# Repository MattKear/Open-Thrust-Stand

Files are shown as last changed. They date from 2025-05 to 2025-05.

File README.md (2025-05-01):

# Open Thrust Stand

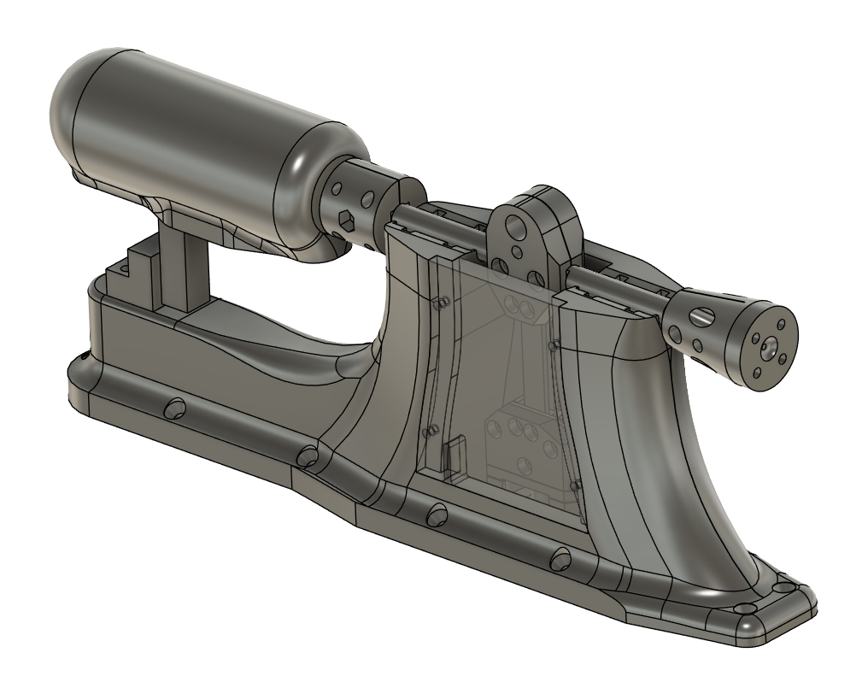
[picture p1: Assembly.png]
Assembly Image

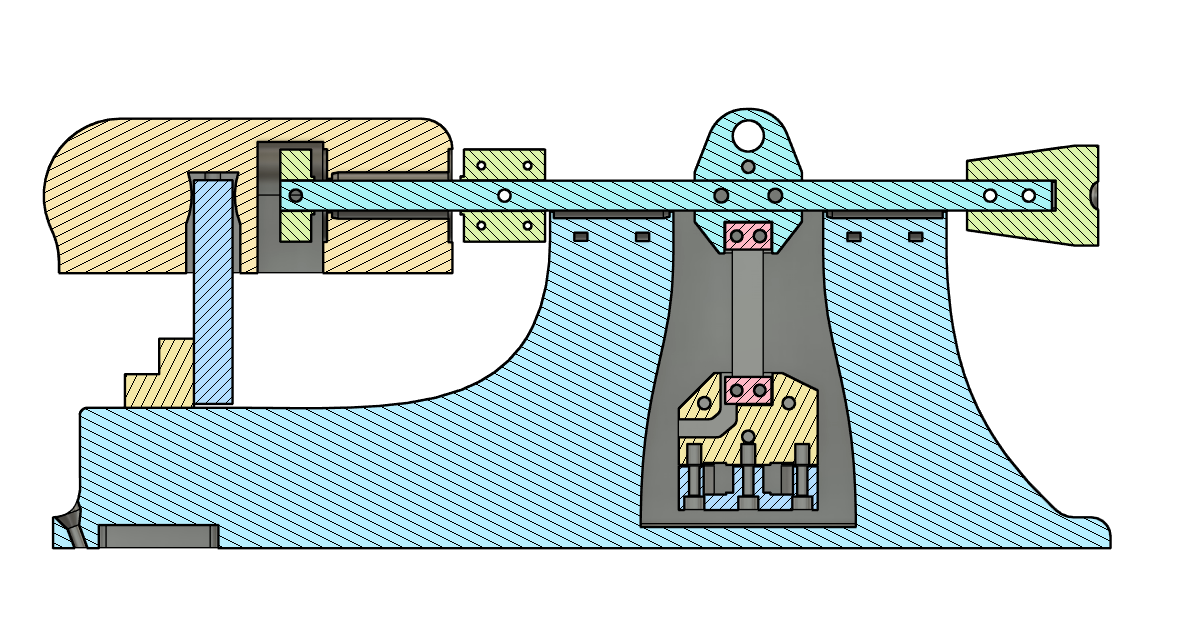
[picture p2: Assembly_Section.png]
Assembly Image


This is a repo of parts, scripts, and information about the ArduPilot-based thrust stand.

The point of this project was to produce a low-cost thrust stand capable:
- Measuring thrust and torque.
- Being controlable from ArduPilot.
- Providing data that can be used for calculating the thrust linearisation coefficient needed for fixed-pitch lifting rotors on ArduPilot vehicles.

Video of original talk: [Youtube Link](https://www.youtube.com/watch?v=xQXkWjY6EkU&list=PLC8WVaJJhN4zE8bW97rS3cNFjsDg0rOaD&index=25)

## Disclaimer
- This project should not be considered as a step-by-step guide.
- It should be considered a difficult project, with numerous tools required to create the final object.
- With 3D prints being in the primary load path, the strength of your parts will vary based on your choosen materials, printer settings, and the printer itself.  Please take care when testing, I accept no liability for any injuries or damage caused.

## License
- **Parts:** CC-BY-SA Creative Commons Attribution Share Alike (https://creativecommons.org/licenses/by-sa/4.0/deed.en)
- **Scripts/Code:** GPLv3 (https://www.gnu.org/licenses/gpl-3.0.en.html)

## Known Design Flaws

Before you start building this thrust stand, you should be aware of some of the flaws with this current design.

1) There is significant rotor blockage from the thrust stand base.  This will effect the measurement of the generated thrust.  The measurements are therefore useful for relative comparisons between propulsion systems that have been measured on this stand.  The blockage does introduce some error in the measurement.  That being said, I found that it produceses reliable and repeatible measurements, you just need to be aware when comparing to other data sets or considering the installed thrust on your vehicle.

2) This design does use one aluminium part from a cheap thrust stand I purchased as part of the background reasearch for this project.  A new part needs to be designed to replace this.  The part in question is the [load cell mount](./Thrust%20Load%20Cell%20Assembly/Load%20Cell%20Mount%20-%20Alu.step)

## Hardware Parts Needed
- M3 & M2 heat set inserts
- Various M3 & M2 allen bolts
- 2x Load Cells
- Wood Screws
- Bearings (Ball Bearings, Thrust Bearings, & Linear Bearings or Graphite Bearings)

>[!NOTE]
>These parts do not include parts needed for the archived enclosure.   

## Electronic Parts Needed
- [SparkFun Qwiic Scale - NAU7802](https://thepihut.com/products/sparkfun-qwiic-scale-nau7802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)
- SPST Switch (Hardware Safety Switch)
- Addressable LED strip supported by ArduPilot (e.g. WS2812b)
- Flight controller that is supported by ArduPilot and has sufficient memory to run scripting. (e.g. CubeOrange or MATEK H743)

## Tools Needed:
- 3D Printers (Mostly FDM but Resin SLA was used for LED Lenses in Enclosure)
- Angle grinder or other form of grinder
- Drill
- Screw Drivers
- Allen Keys
- Soldering Iron

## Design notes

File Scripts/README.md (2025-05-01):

# Thrust Stand
The scripts described here, utilise ArduPilot's Lua scripting enviroment to effectively convert ArduCopter into a Thrust Stand.

This has the advantage that the thrust stand will work with any ESC/protocol that ArduCopter supports.  Also, it allows for the script/workflow for to be easily customized to utilize all peripherals and sensors that are supported by ArduCopter.  For example, to measure RPM, just add an RPM sensor/ESC telemtry and the data will be added to the ArduCopter log.  Want to use WiFi telemetry to wirelessly operate the thrust stand? simply add an already supported wifi radio.

## Setup Instructions

Minimum hardware requirements:
- Toggle Switch - Configured as button 1 in AP button library.
- 10 Addressable LEDs for throttle bar. (not used in Thrust_Stand_Simple.Lua)
- SparkFun Qwiic Scale - NAU7802.  Only 1 is required for Thrust only measurements. A second is required for the optional torque measurement.  Note: to use two of these load cells either your flight controller must have 2 I2C buses available or you need an MUX, as the addresses are not configurable on those devices.

Firmware requirements:
- Thrust_Stand.Lua is more advanced and requires building copter from [this branch](https://github.com/MattKear/ardupilot/tree/Thrust_Stand_XL) to provide access to the thrust linearisation lua bindings that I have added.
- Thrust_Stand_Simple.Lua should run on stable copter (4.4 onwards).

## Connections & Setup
- Thrust load cell amplifier must be connected to I2C bus 1.
- Optional Torque load cell amplifier must be connecter to I2C bus 2 and `THST_ENAB_TORQ` must be set to 1.
- The ESC should be plugged into the flight controller output that you would use normally for flight (e.g. Servo output, CAN, etc) and configured as the `Motor1` (33) output. As this script is using ArduCopter, all throttle protocols supported by ArduCopter are supported by this script.
- A toggle switch must be configured as button 1, to act as a safety switch (see: https://ardupilot.org/copter/docs/common-buttons.html)

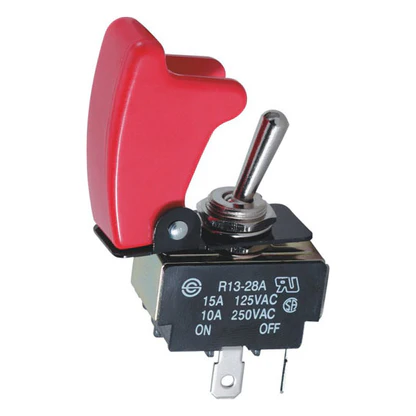
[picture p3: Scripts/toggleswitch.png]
Example toggle switch


## Calibrations

The load cell outputs a unitless number that requires calibration parameters to convert to loads in your desired units.  To calibrate, apply known loads to the load cells to derive the necessary calibration parameters.  For each load cell a gradient and an offset are required.  The calibration parameters to be set are:
- **`THST_CAL0_THST`:** Thrust load cell calibration, zero offset.
- **`THST_CALM_THST`:** Thrust load cell calibration, gradient.
- **`THST_CAL0_TORQ`:** Torque load cell calibration, zero offset.
- **`THST_CALM_TORQ`:** Torque load cell calibration, gradient.

Apply a series of different loads (weights are often the easiest) and look at the corresponding `MAV_THST_RAW` or `MAV_TORQ_RAW` telemetry streams on the GCS.  Plotting raw output vs applied load should give you a straight line.  Calculate the gradient and zero offset using a line of best fit (linear regression).  Enter the obtained values into the parameters mentioned above.  Finally, re-apply a load and check either `MAV_THRUST` or `MAV_TORQUE` on the GCS to make sure that the reported value matches the applied load.

-  Raw measurement from the thrust load cell amplifier.
- **`MAV_TORQ_RAW`:** Raw measurement from the torque load cell amplifier.

## Example Test Run

1. Power on the flight controller.

2. Connect the GCS to the flight controller.  This can be in any means you would like, just like with a normal copter.  e.g. You can use USB, WiFi, or some other telemetry radio.

3. Power on your propulsion system with either a battery or power supply.

4.Set the flight mode that corresponds to the thrust stand mode that you would like to use.

5. Perform the remaining checks as suggested below to make sure your sensors are all reporting correctly.

6. When you are ready to start your test, toggle the safety switch to prepare the system for test.

7. Arm copter from the GCS and the test will begin.

8. Once the test has completed the throttle will hold at `MOT_SPIN_MIN`.  Toggle the safety switch.  This will both disarm ArduCopter and "Safe" the system. 

## Saftey Switch

The safety switch is there to provide a quick and easy way to stop the test in an emergency.  If at any point during the test there is an issue or you simply want to stop the test, flick the switch and the throttle will be instantly zeroed and ArduCopter will be disarmed.

>[!NOTE]
>If you arm the system with the switch still in the "Safe" position, the test will not begin until the switch has been moved to the "Active" position.

## Checklists

### Power on Checks
- Power on propulsion system (Battery or power supply)
- Check for correct voltage measurement.
- Check/set current limit (`THST_CUR_LIM`).

### “Pre-Flight” Checks
- Check thrust load cell reporting correctly (number is moving and in correct direction).
- if applicable, check torque Load cell reporting correctly (number is moving and in correct direction).
- If applicable, check `RPM1_SCALE` = 1 is set for eRPM  measurement,
- Set `MOT_SPIN_MIN` (use Copter's motor test) [`THST_ENBL_TEST` = 1]
- Check/set for thrust linearisation enabled [`THST_USE_LIN`].  Pick whichever is appropriate for the test.
- Check `MOT_SPIN_MAX` = 1.0
- Check `MOT_PWM_MIN` (usually set 1000)
- Check `MOT_PWM_MAX` (usually set 2000)
- Run up to 50% throttle check.
- Calibrate Thrust and Torque load cells if necessary.

### Test Checks

- Set test mode.

#### Throttle Ramp Mode

-	Set `THST_HOLD_S` (s) to the length of time to hold throttle at each step.
-	Set `THST_MAX_THR` (%) [0 - 100] to set the max throttle.
-	Set `THST_RAMP_STEP` [0.01 - 1.0]

#### Transients / Step-Change Mode

-	Set `THST_HOLD_S` (s) to the length of time to hold the step change.
-	Set `THST_MAX_THR` (%) [0 - 100] to the max throttle to set the step change to.
-	Set `MOT_THST_HOVER` [0.0 - 1.0]
Note: Throttle will step hover throttle +/- (max throttle – hover).  Ensure set to allow symmetric steps.

#### Frequency Sweep / Throttle Chirp Mode
-	Throttle/thrust output is between MOT_SPIN_MIN and MOT_SPIN_MAX
-	Set `THST_HOLD_S`(s) to the length of time to hold the initial trim state. Usually set 3 s.
-	Set `THST_MAX_THR` (%) [0 - 100] to the max throttle to set the step change to.
-	Set `MOT_THST_HOVER` [0.0 - 1.0] this is the centre/mean of the sin wave
-	Set `THST_NSE_RAT` – the noise ratio or amplitude.
-	Set `THST_OMEGA_MIN` (rad/s) (default = 0.3)
-	Set `THST_OMEGA_MAX` (rad/s) (default = 12)

##### Test Procedure:

- Log air temperature, relative humidity, and pressure.
- Arm ArduCopter via GCS.
- Switch toggle safety switch.
- Throttle will ramp up and test will begin.
- Test will be performed  automatically, as per configuration.
- Throttle will ramp down and sit at `MOT_SPIN_MIN` once test has completed.
- Switch toggle safety switch to both safe and disarm system.

## Test Modes

Copter flight modes are used as a proxy for thrust stand modes. The below describes which copter modes correlates to the thrust stand modes.

You must set the flight modes below, via the GCS, to use the corresponding thrust stand modes described below.

- Ensure that you have set the mode via the GCS before you arm the thrust stand, to perform the desired test.

- **Stabilise:** Stepped throttle ramp for expo calculations
- **Alt_Hold** - Throttle mode hold, ramps to `THST_MAX_THR` and holds for `THST_HOLD_S`
- **Acro** - Throttle steps, ramps to `MOT_THST_HOVER`, and then step changes to `THST_MAX_THR`
- **Guided_NoGPS** – (System ID) Throttle chirps/frequency sweeps

## Parameter Definitions

- **`THST_CAL0_THST`:** Thrust load cell calibration, zero offset.
- **`THST_CALM_THST`:** Thrust load cell calibration, gradient.
- **`THST_CAL0_TORQ`:** Torque load cell calibration, zero offset.
- **`THST_CALM_TORQ`:** Torque load cell calibration, gradient.
- **`THST_CUR_LIM`:** Current limit. If battery monitor measures a current above this value the throttle will be instantly zeroed and the test will stop.  Safety switch has to be cycled to allow another test to start again.
- **`THST_MAX_THR`:** Maximum throttle used. In a ramp test the throttle will ramp between 0 and max.  In all other test modes the throttle will be constrained by this value. 0 to max throttle is within spin min and max.
- **`THST_HOLD_S`:** Hold time in seconds.  In ramp test, this is the step dwell time.  In the transient, step test, this is the dwell time to hold the throttle at between step inputs.
- **`THST_ENBL_TORQ`:** Used to enable use of 2nd load cell for torque measurements. 0 = disabled, 1 = enable torque.
- **`THST_ENBL_TEST`:** Set to 1 (allow) to enable copters motor test from the GCS.  Whenever a thrust stand run is started this param is automatically returned to 0 (disabled) with a set and save.  This is required to stop the script from overriding the output when copter is trying to do its motor test.
- **`THST_OMEGA_MIN`:** Minimum frequency (rad/s) for throttle chirp test.
- **`THST_OMEGA_MAX`:** Maximum frequency (rad/s) for throttle chirp test.
- **`THST_NSE_RAT`:** Noise ratio to be applied during chirp test. Ratio of max throttle.
- **`THST_RAMP_STEP`:** Spacing between throttle steps in ramp test mode.  E.g. 0.1 = 10% throttle steps.
- **`THST_USE_LIN`:** – 0 = throttle control, 1 = thrust control.  When enabled thrust to throttle linearisation from multi-rotor code is used. **(Not enabled in Thrust_Stand_Simple.lua)**

- **`MOT_PWM_MIN`:** Copter `MOT_PWM_MIN` used in throttle output calculation. See here for definition: https://ardupilot.org/copter/docs/parameters.html#mot-pwm-min-pwm-output-minimum
- **`MOT_PWM_MAX`:** Copter `MOT_PWM_MAX` used in throttle output calculation. See here for definition: https://ardupilot.org/copter/docs/parameters.html#mot-pwm-max-pwm-output-maximum
- **`MOT_SPIN_MIN`:** Copter `MOT_SPIN_MIN` used in throttle output calculation. See here for definition: https://ardupilot.org/copter/docs/parameters.html#mot-spin-min-motor-spin-minimum
- **`MOT_SPIN_MAX`:** Copter `MOT_PWM_MIN` used in throttle output calculation. See here for definition: https://ardupilot.org/copter/docs/parameters.html#mot-spin-max-motor-spin-maximum

- **`MOT_THST_EXPO`:** Used in thrust linearisation calculation, if THST_USE_LIN is enabled.

- **`MOT_THST_HOVER`:** used for throttle step transient mode.  This is the middle throttle setting and the the throttle is stepped +/- `THST_RAMP_STEP` about this value.

## Live Outputs to GCS

Live telemetry data can be seen from the script. The following are output at 2 Hz:
- **`MAV_THST_RAW`:** Raw measurement from the thrust load cell amplifier.
- **`MAV_TORQ_RAW`:** Raw measurement from the torque load cell amplifier.
- **`MAV_THRUST`:** Calibrated thrust calculation from thrust load cell.
- **`MAV_TORQUE`:** Calibrated thrust calculation from torque load cell.

- This data can be viewed on the GCS just like any other telemetry data from Copter.  For example, in mission planner, the "Quick" tab will give numerical read outs and the "Tuning" graphs will plot the data trend vs time.

## Logging

All data is stored in ArduCopter *.bin log files. The thrust and torque data is stored in the **THST** log field.  All other data is stored in the usual log fields. E.g Battery monitor stores current and voltage data, RPM for rpm data etc.

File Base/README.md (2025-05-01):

# Thrust Strand Base

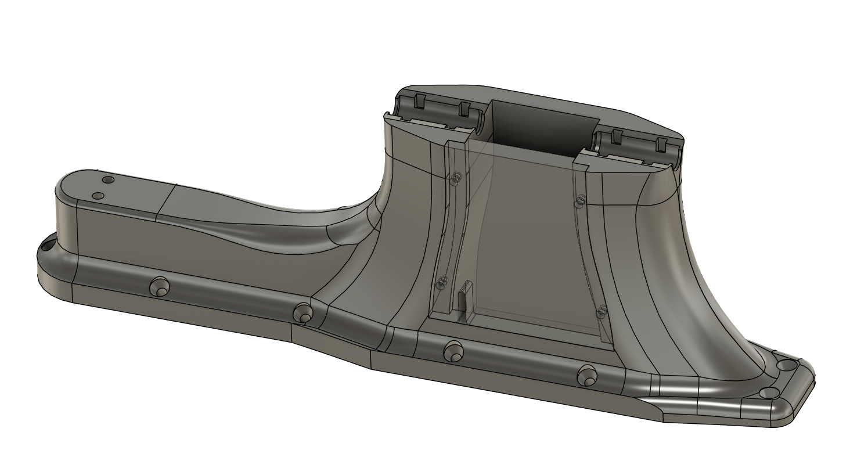
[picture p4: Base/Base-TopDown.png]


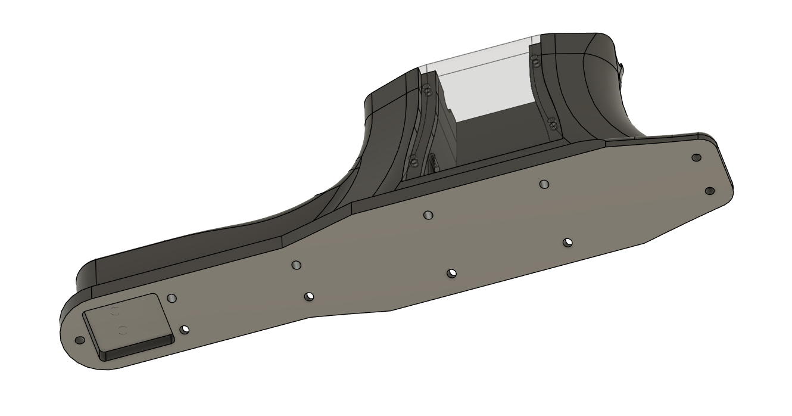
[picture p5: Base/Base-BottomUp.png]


Wood Screws are used to afix the base to a strong flat surface.

M2 bolts and heat-set inserts are used to secure the side cover in place.

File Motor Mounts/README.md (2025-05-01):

# Motor Mounts

The motor mounts are easily swappable, making it easy to test different motors.  Here are a few mounts that have already been made.

## 16 x 16 Hole Spacing
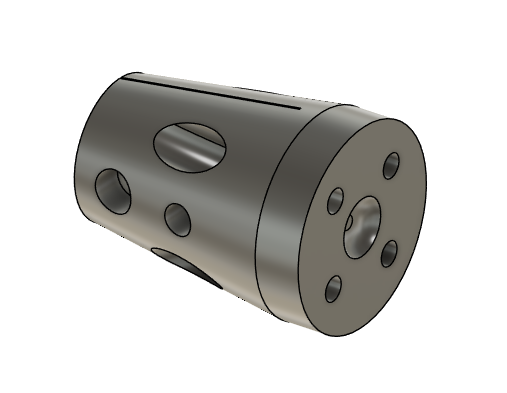
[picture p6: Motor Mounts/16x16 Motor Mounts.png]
16 x 16 Hole Spacing


## 19 x 19 Hole Spacing
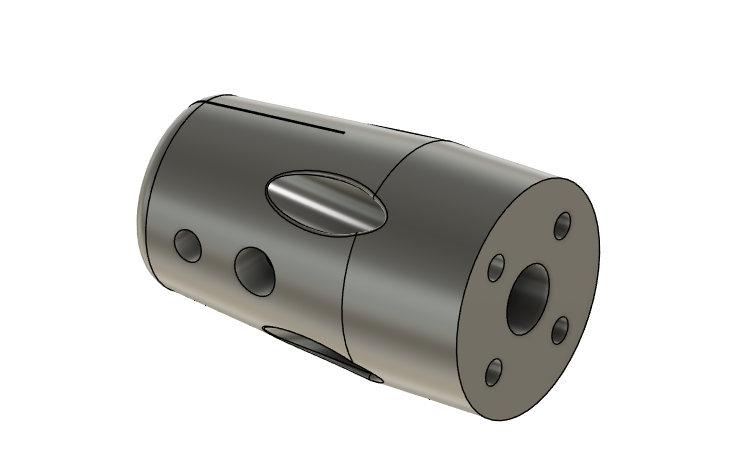
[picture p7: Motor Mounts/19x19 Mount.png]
19 x 19 Hole Spacing


## MAD Polar Motor Mount
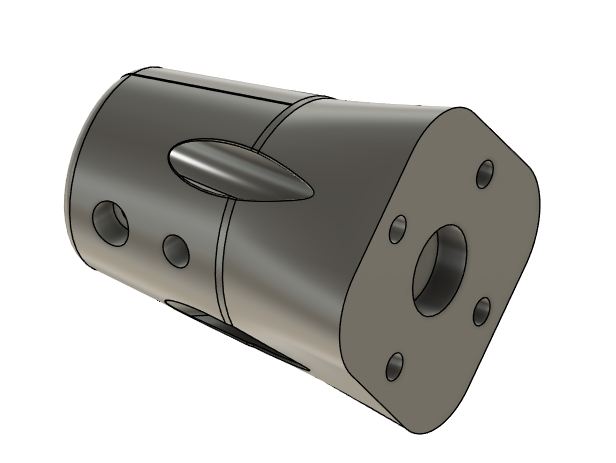
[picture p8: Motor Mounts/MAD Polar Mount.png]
MAD Polar Motor Mount


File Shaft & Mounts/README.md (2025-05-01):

# Shaft & Bearing Mounts

In this directory you will find the bearing retainers and the guides for grinding the flats into the linear rail. 

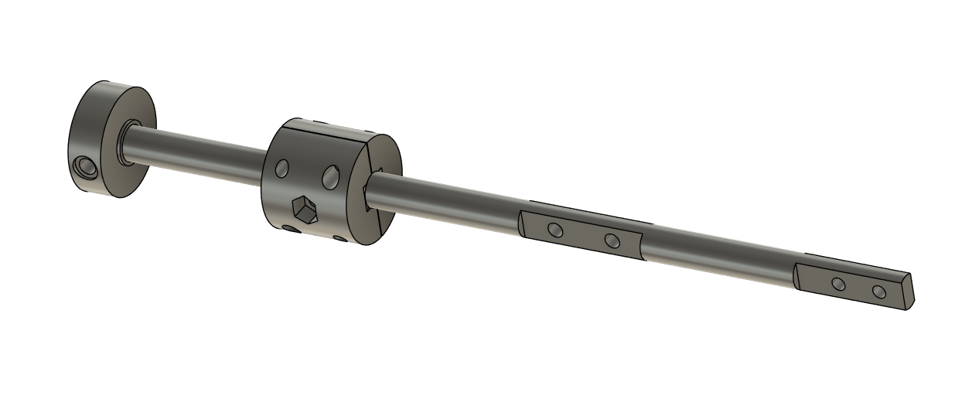
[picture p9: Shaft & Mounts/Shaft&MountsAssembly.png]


# Grinding Guides

The 3D printed grinding guides are used to clamp around the shaft and provide a guide of where to grind away the flats on the linear rail.

You will need to grind away the flats gradually, to avoid building up too much heat in the rail and the 3D prints.  Excessive heating of the rail could warp it and cause more friction in the system.  Melting of the 3D prints will lead to an inaccurate guide.

Rest assured, Once you have grinded past the hardend surface on the linear rail, the steel is quite soft beneath it, so it is easy to drill the holes in.

The holes in the guide are sized so that an M3 will bite into the plastic.  Heat set inserts are not needed in this part.

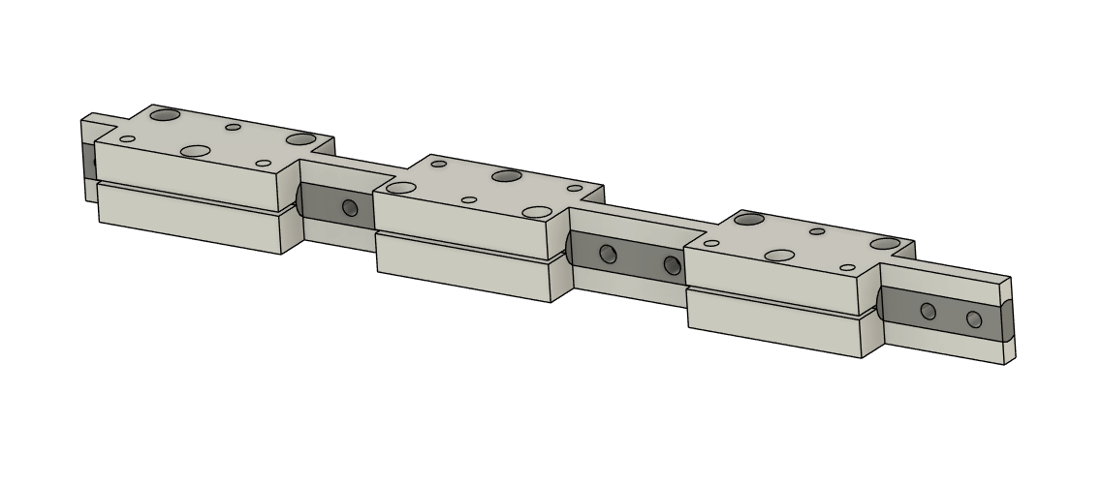
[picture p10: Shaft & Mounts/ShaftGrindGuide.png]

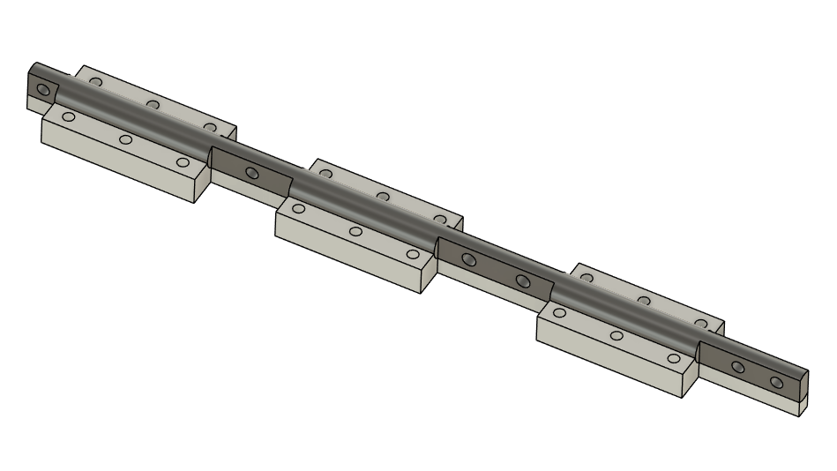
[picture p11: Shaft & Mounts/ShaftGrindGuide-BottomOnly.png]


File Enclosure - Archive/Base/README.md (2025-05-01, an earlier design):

# Enclosure Base

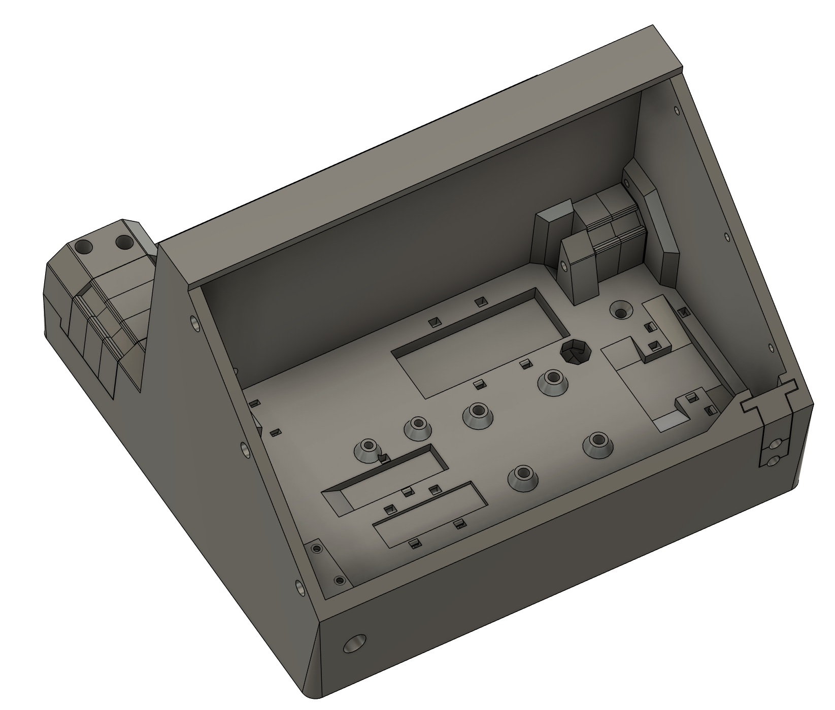
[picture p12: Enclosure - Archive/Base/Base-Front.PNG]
Enclosure Base Front

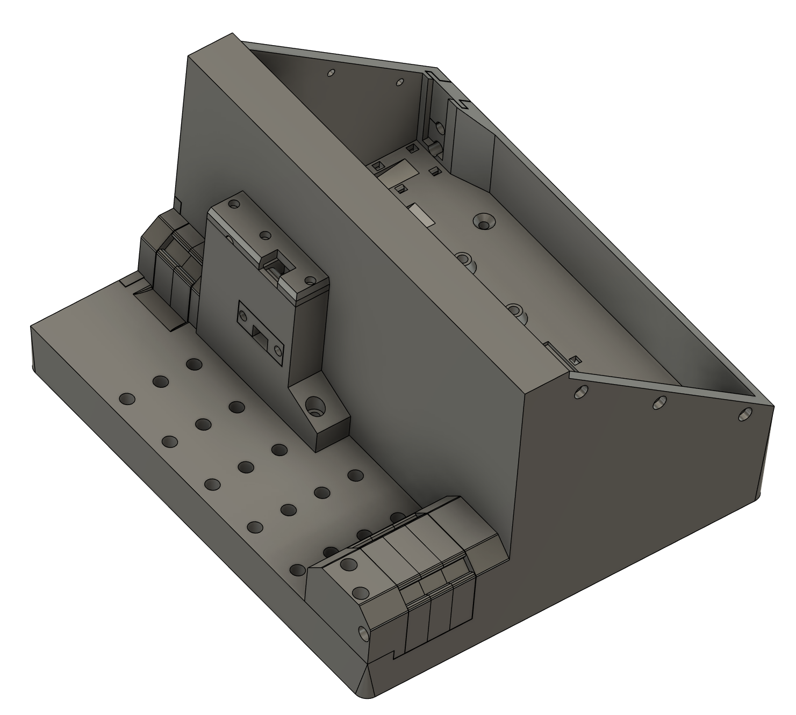
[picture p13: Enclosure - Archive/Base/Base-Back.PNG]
Enclosure Base Back


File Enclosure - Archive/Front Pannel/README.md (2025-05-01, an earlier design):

# Enclosure Front Pannel

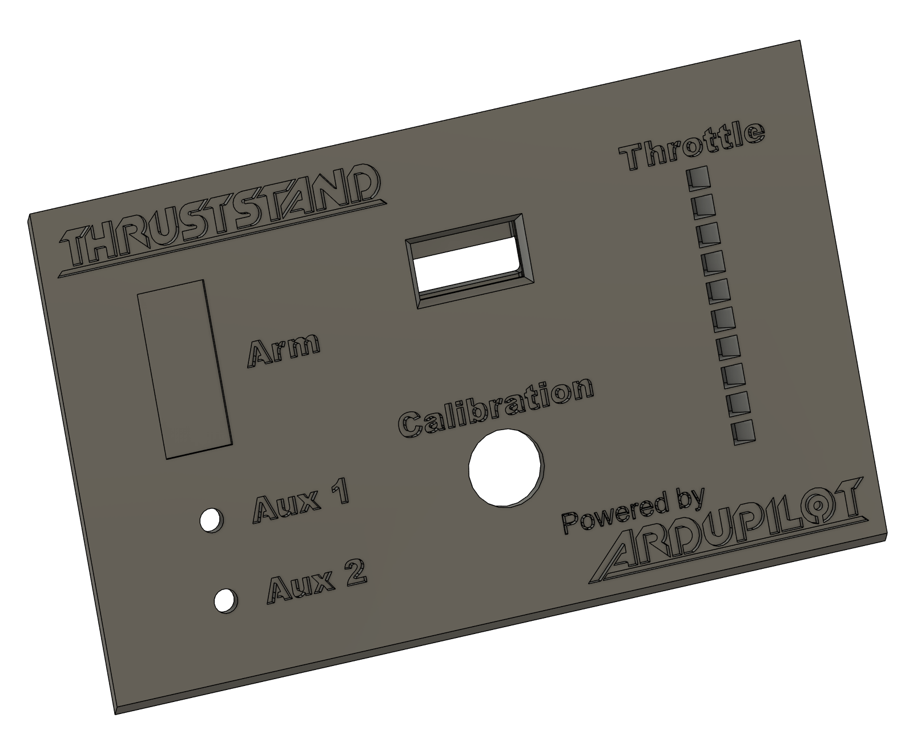
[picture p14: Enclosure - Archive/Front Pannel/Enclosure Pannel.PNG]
Enclosure Pannel


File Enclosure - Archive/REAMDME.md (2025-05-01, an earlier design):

# Enclosure

I have marked this part as `archived` as it is not particularly fit for purpose.  I do not use it anymore, and I would recommend that you just attach the parts to flat surface (this is what i do now). It makes it a lot easier for modifying and fiddling with the setup. You can always fix that surface into a project box should you wish.

If you use any of the later versions of the script I have posted, I have removed the use of the I2C screen and the calibration button.  I have moved to a process of using Mission Planned to control the thrust stand from instead so the screen and button were no longer needed.

I kept the arming switch and LED bar though.

I am posting these files here as some people may still want to make use of them.

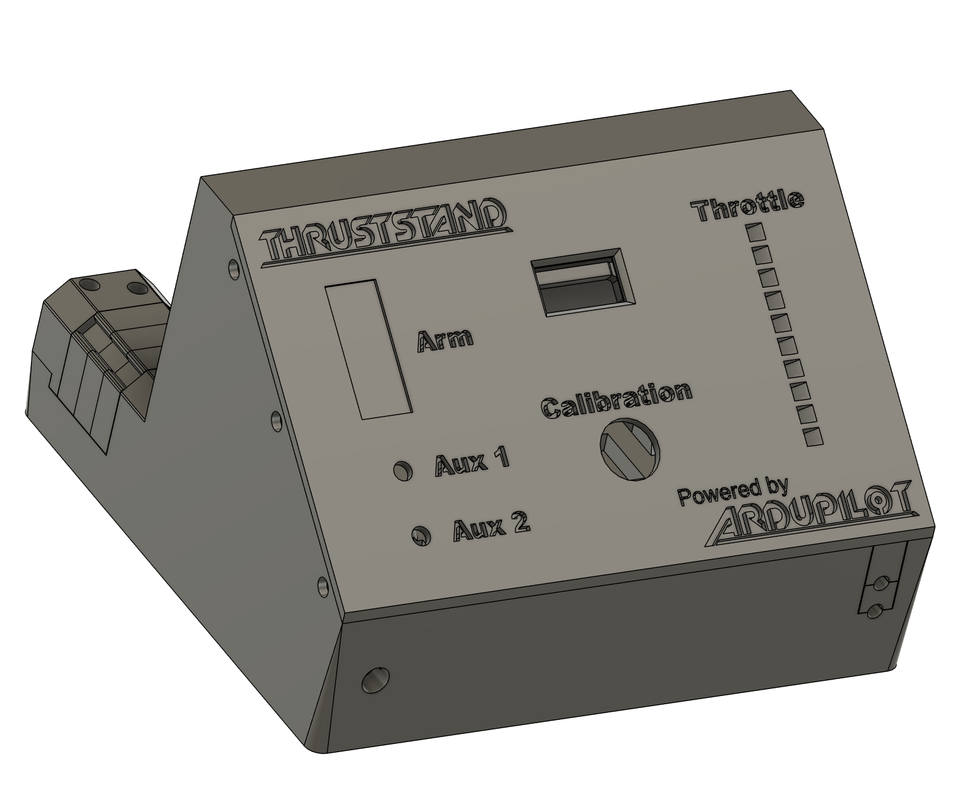
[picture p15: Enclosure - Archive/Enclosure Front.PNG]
Enlosure Front

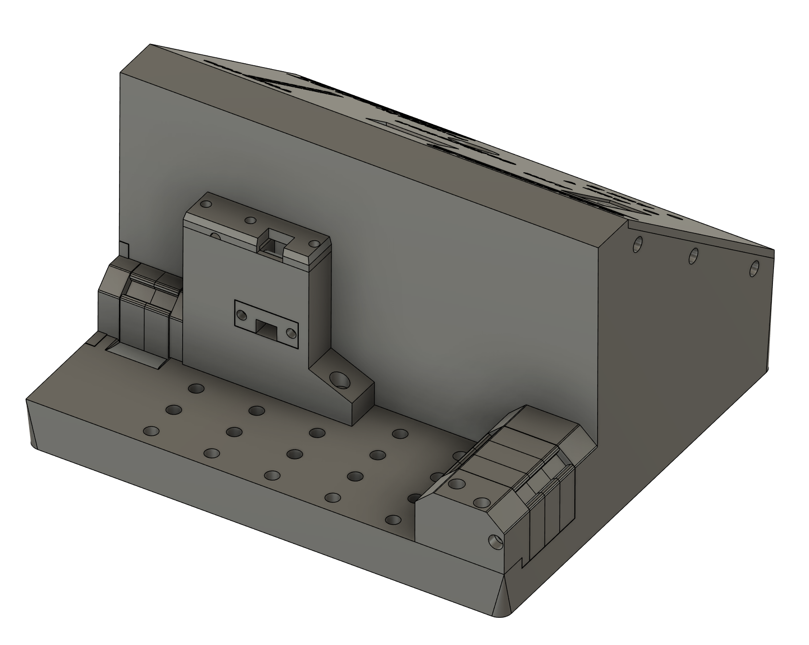
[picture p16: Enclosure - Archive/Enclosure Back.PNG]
Enlosure Back


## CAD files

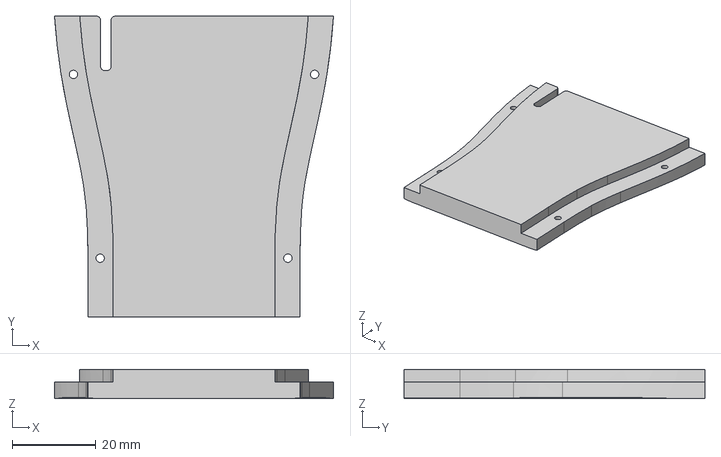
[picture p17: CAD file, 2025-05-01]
Base/Base Cover - 3D Print.step
66.6 x 71.8 x 7.00 mm

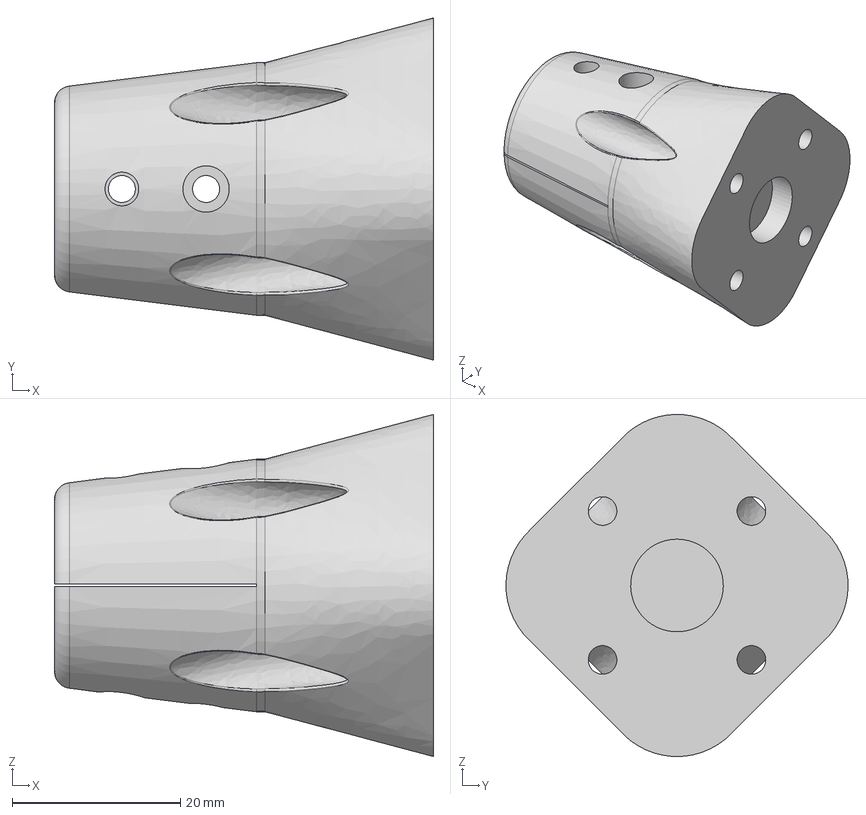
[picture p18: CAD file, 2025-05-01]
Motor Mounts/MAD Polar Mount - 3D Print.step
45.0 x 40.6 x 40.6 mm

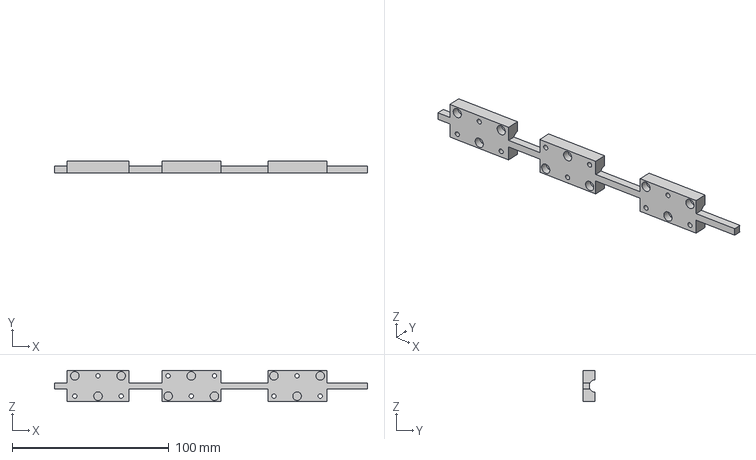
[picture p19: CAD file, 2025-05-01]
Shaft & Mounts/Shaft Grind Guide Top - 3D Print.step
200.0 x 7.60 x 20.0 mm

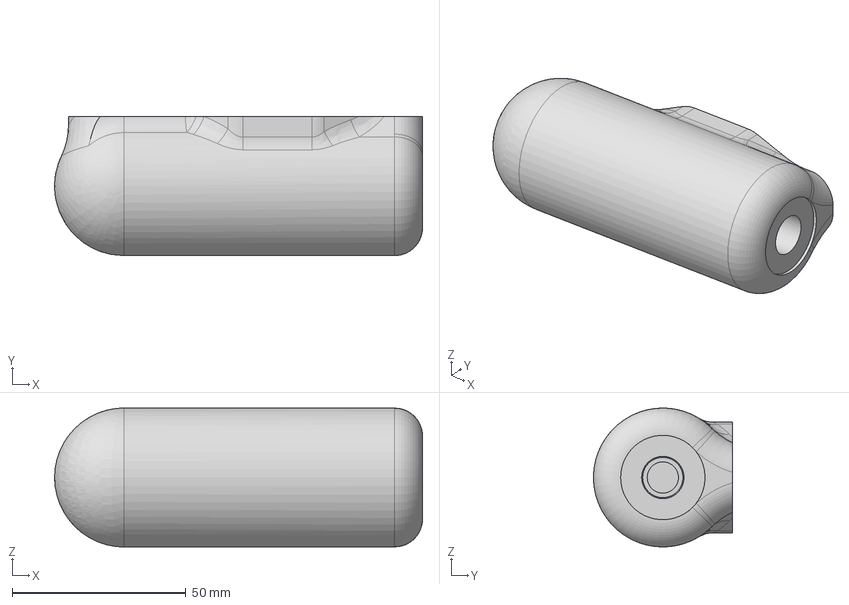
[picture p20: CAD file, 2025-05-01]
Thrust Load Cell Assembly/Thrust Cell Interface - 3D Print.step
106.0 x 40.1 x 40.0 mm

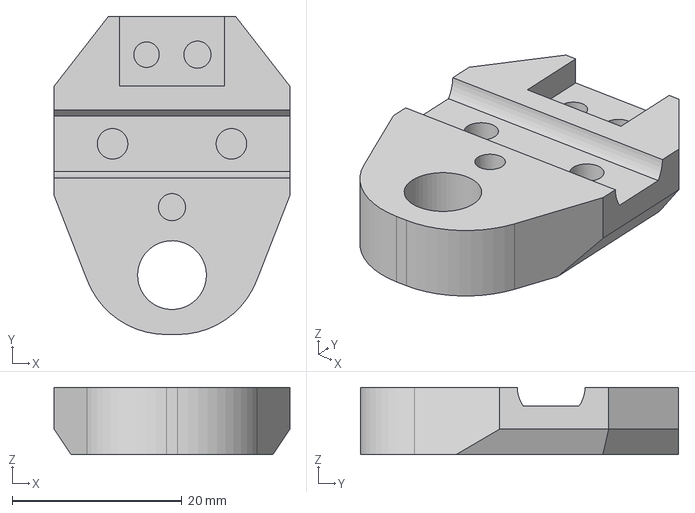
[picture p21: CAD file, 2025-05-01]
Torque Load Cell Assembly/TorqueShaftClampLeft-3DPrint.step
27.8 x 37.5 x 7.90 mm

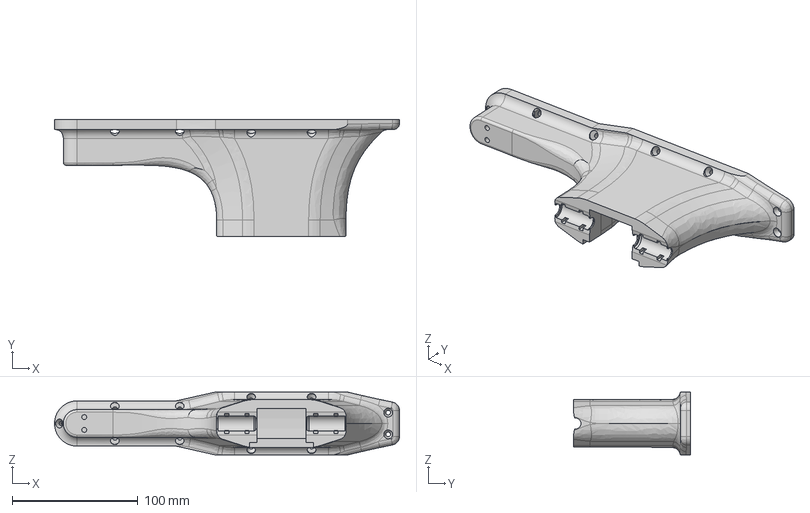
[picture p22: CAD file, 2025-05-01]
Base/Base Body - 3D Print.step
274.3 x 93.0 x 50.0 mm

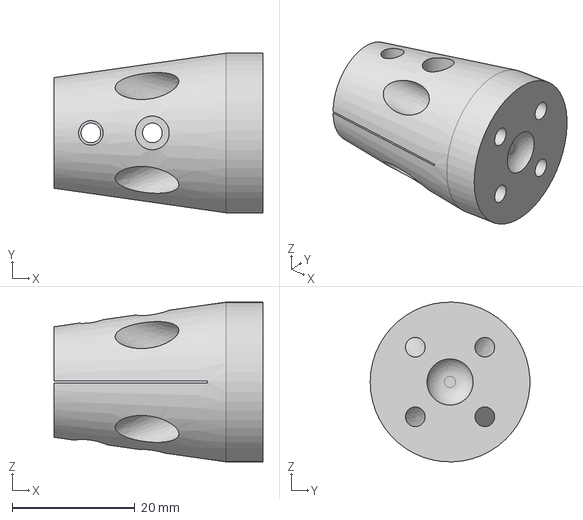
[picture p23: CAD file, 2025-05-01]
Motor Mounts/16x16 Motor Mount - 3D Print.step
34.0 x 26.0 x 26.0 mm

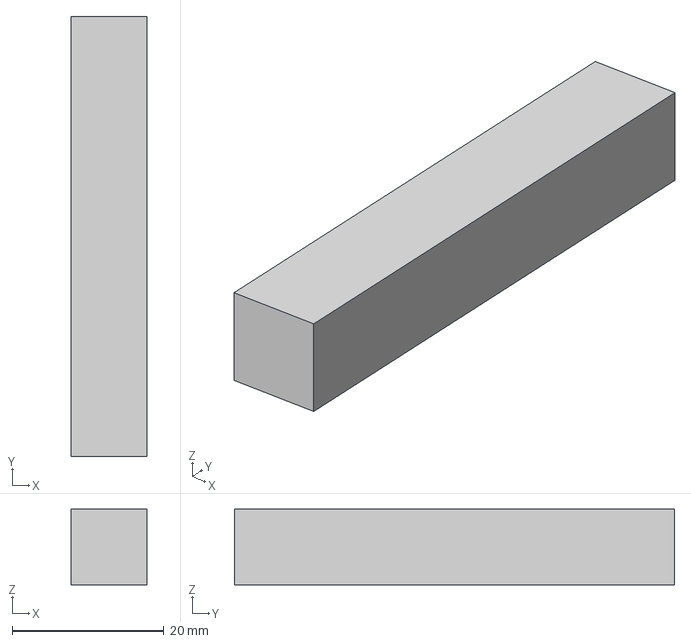
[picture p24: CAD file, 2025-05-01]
Thrust Load Cell Assembly/Load Cell Stand In.step
10.00 x 58.0 x 10.0 mm

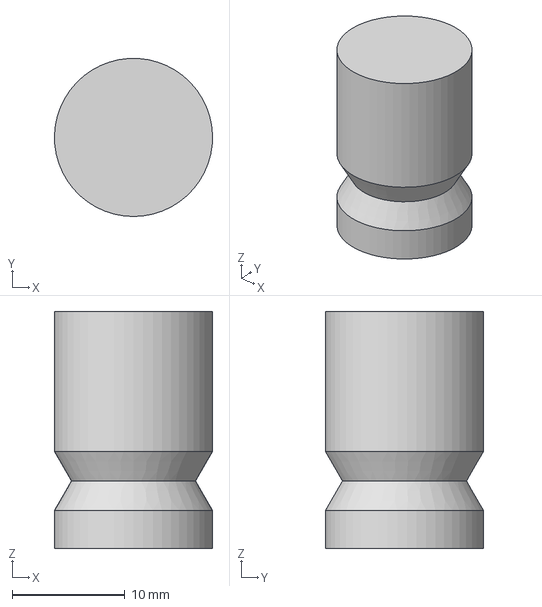
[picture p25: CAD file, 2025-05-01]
Torque Load Cell Assembly/End Cap-3DPrint.step
14.0 x 14.0 x 21.0 mm

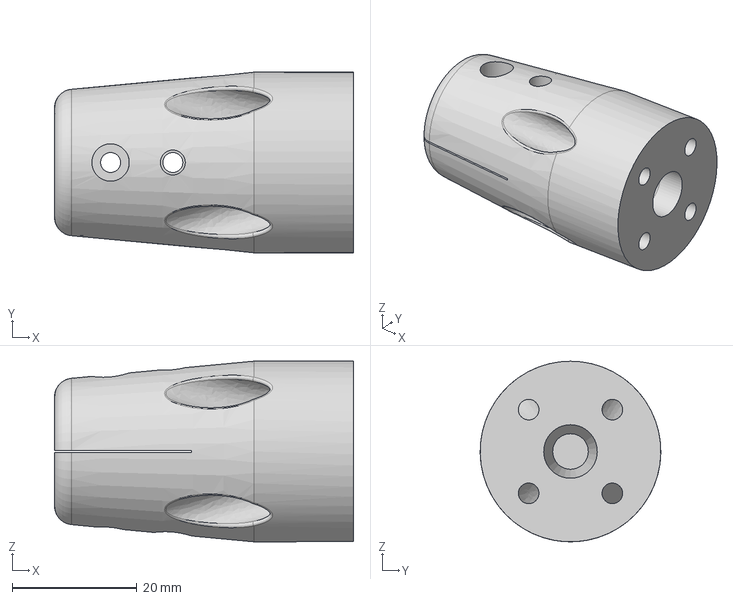
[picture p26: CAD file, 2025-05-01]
Motor Mounts/19x19 Motor Mount - 3D Print.step
48.0 x 29.0 x 29.0 mm

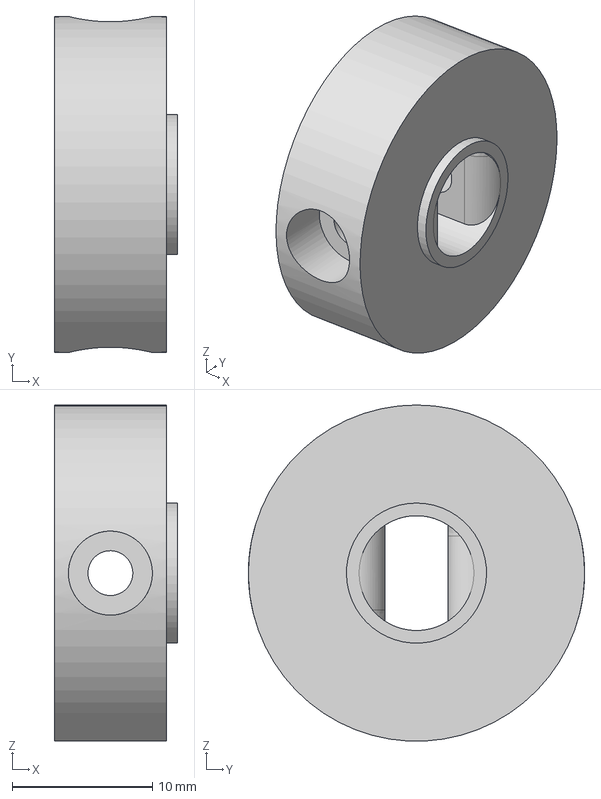
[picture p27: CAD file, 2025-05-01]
Shaft & Mounts/Thrust Bearing End - 3D Print.step
8.80 x 24.0 x 24.0 mm

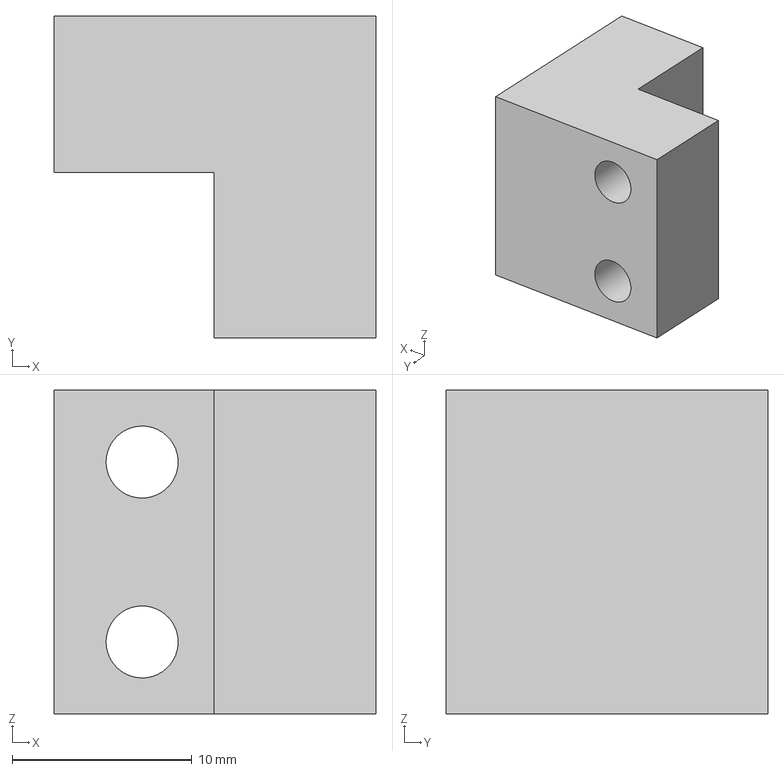
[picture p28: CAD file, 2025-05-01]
Thrust Load Cell Assembly/Load Cell Mount - Alu.step
17.9 x 17.9 x 18.0 mm

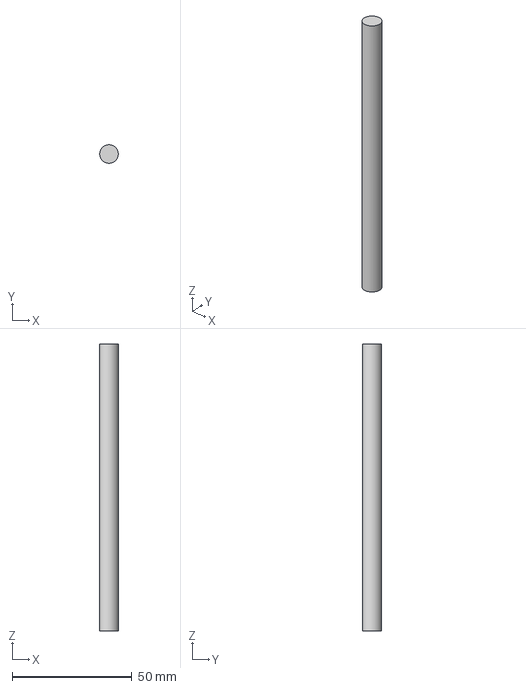
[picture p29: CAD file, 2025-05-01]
Torque Load Cell Assembly/Torque Applicator-Alu.step
7.79 x 7.80 x 120.0 mm

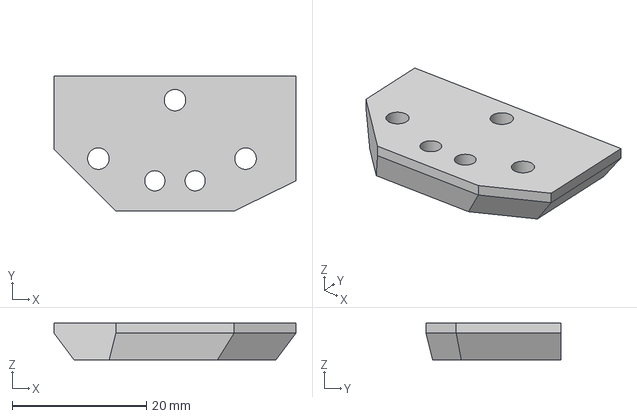
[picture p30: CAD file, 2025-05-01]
Torque Load Cell Assembly/Torque Cell Interface Lid - 3D Print.step
36.0 x 20.1 x 5.50 mm

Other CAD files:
Shaft & Mounts/Shaft Grind Guide Bottom - 3D Print.step
Shaft & Mounts/Shaft-Steel Linear Rail.step
Torque Load Cell Assembly/Torque Cell Interface Bearing Retainer - 3D Print.step
Torque Load Cell Assembly/Torque Cell Interface Case - 3D Print.step
Enclosure - Archive/Base/Basy-Main-Body - 3D Print.step
Enclosure - Archive/Base/ESC AC Terminal Lock - 3D Print.step
Enclosure - Archive/Base/ESC Power Terminal Lock - 3D Print.step
Enclosure - Archive/Base/PWM Pin Holder - 3D Print.step
Enclosure - Archive/Base/Pendant Clamp Lid - 3D Print.step
Enclosure - Archive/Base/Power Cable Blank - 3D Print.step
Enclosure - Archive/Base/Power Cable Spacer - 3D Print.step
Enclosure - Archive/Base/Sheilded Wire Clamp - 3D Print.step
Enclosure - Archive/Base/Telem & Signal Terminal Block - 3D Print.step
Enclosure - Archive/Base/Terminal-Purchased Part.step
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

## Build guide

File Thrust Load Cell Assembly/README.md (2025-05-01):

# Thrust Load Assembly

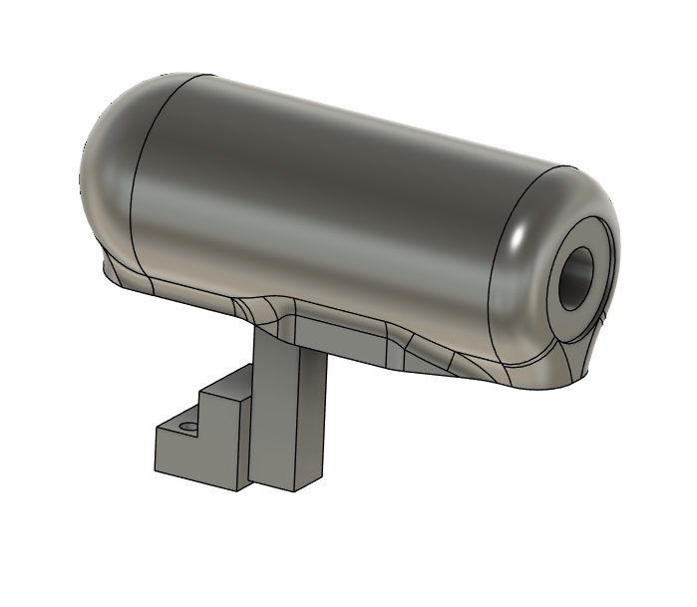
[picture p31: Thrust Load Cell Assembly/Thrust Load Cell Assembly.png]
Thrust Load Cell Assembly

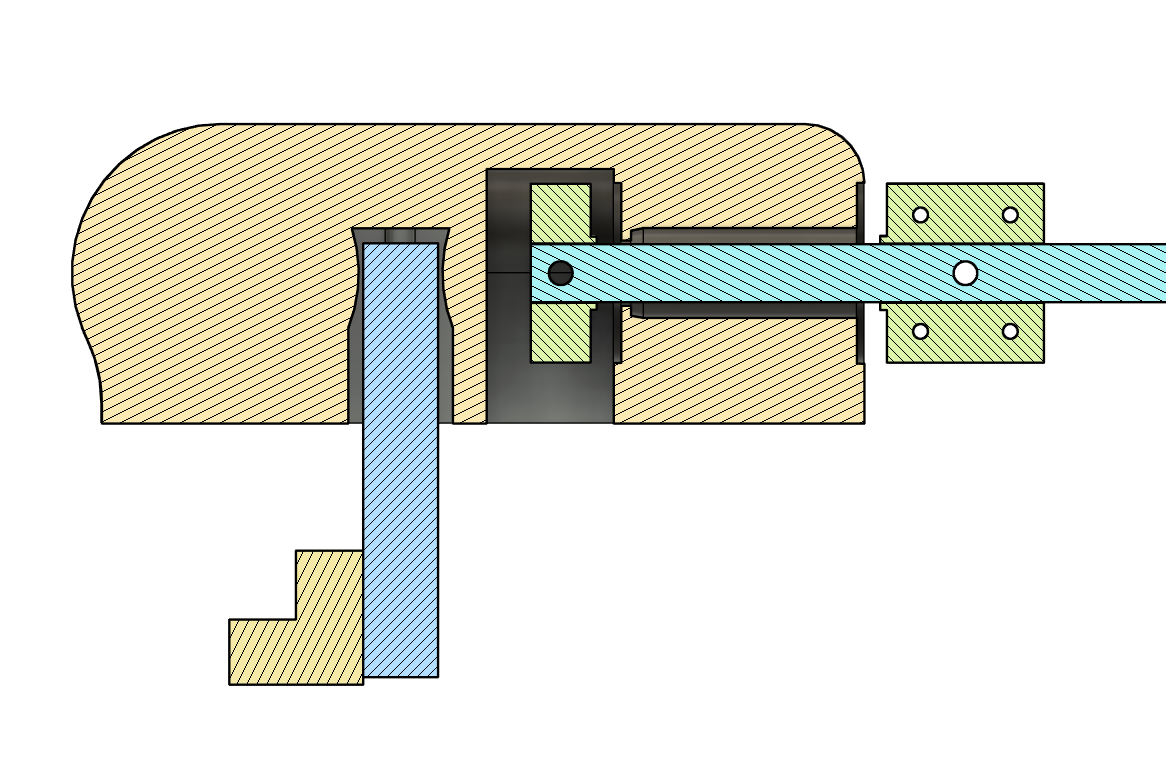
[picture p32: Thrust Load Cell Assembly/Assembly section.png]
Thrust Load Cell Assembly Section


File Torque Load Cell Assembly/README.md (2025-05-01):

# Torque Load Cell Assembly

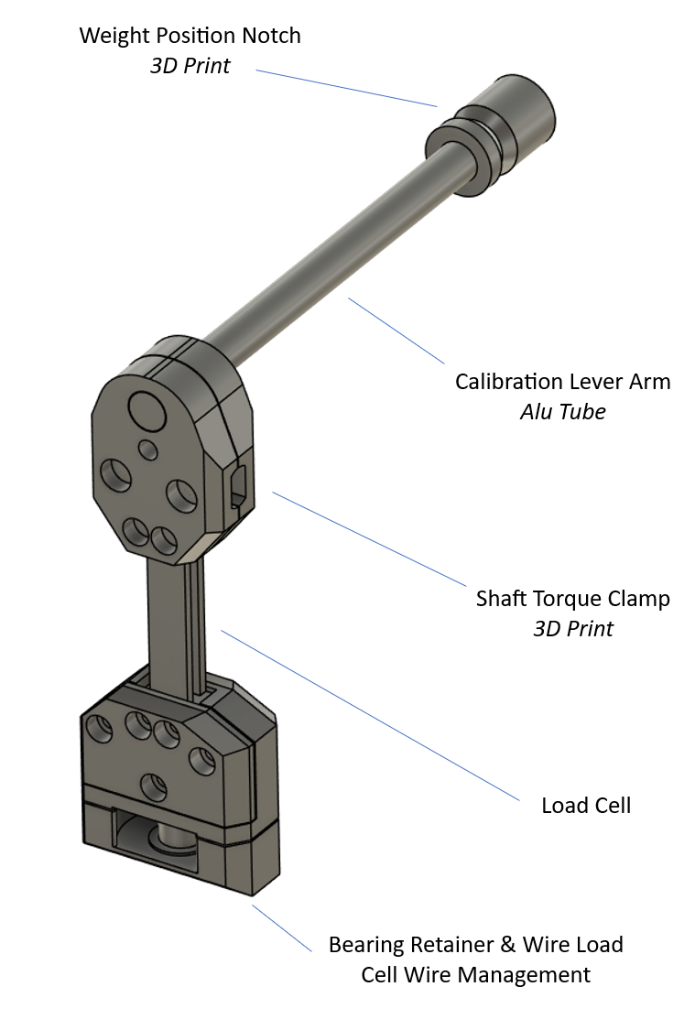
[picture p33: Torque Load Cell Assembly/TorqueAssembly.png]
Torque Load Cell Assembly


Assembly is used to clamp on to main shaft, translating all torque reaction through the load cell. Bearing in bottom is used to maintain a point load with minimal friction resistance in fore/aft translations. 

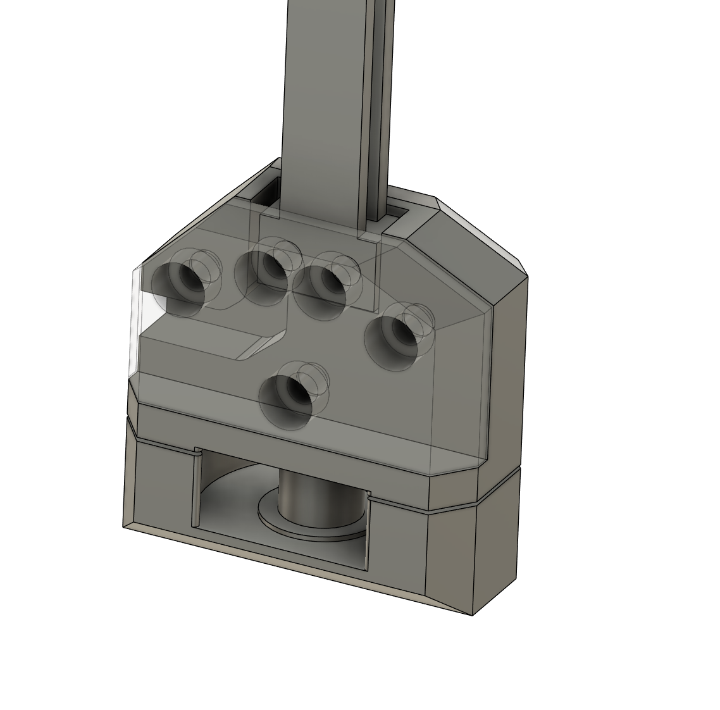
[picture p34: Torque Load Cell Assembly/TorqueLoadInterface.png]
Torque Load Cell Assembly


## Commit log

2025-05-01 start repo
    [16x16 Motor Mount - 3D Print.step, 19x19 Motor Mount - 3D Print.step, Base Body - 3D Print.step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]
2025-05-01 Add enclosure files
    [Basy-Main-Body - 3D Print.step, ESC AC Terminal Lock - 3D Print.step, ESC Power Terminal Lock - 3D Print.step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]
